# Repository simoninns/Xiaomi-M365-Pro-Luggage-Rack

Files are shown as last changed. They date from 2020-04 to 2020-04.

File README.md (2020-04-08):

# Xiaomi-M365-Pro-Luggage-Rack

A 3D printable luggage rack design for the Xiaomi M365 Pro electric scooter that does not prevent the folding down of the handlebars for carrying.

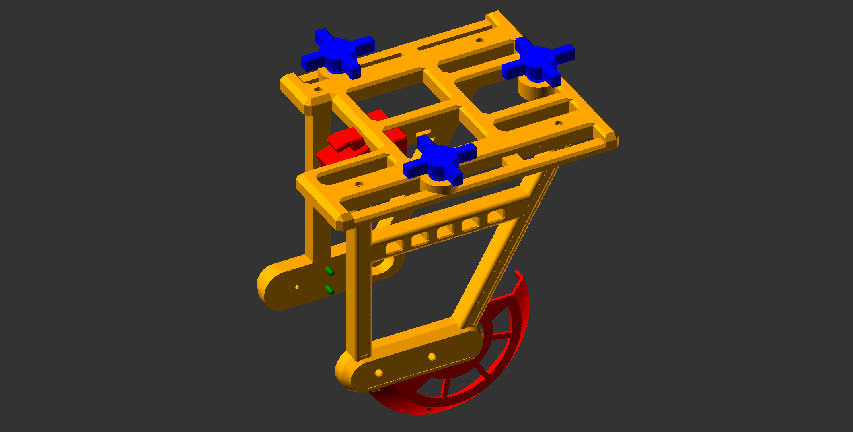
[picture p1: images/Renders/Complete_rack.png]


# Overview

The design includes a 3 part rack (left stay, right stay and rack surface) that mounts in place of the existing side covers of the M365 pro scooter.  The rack is designed to fit around the existing hardware (such as the disc brake calliper) without the need to alter any parts.  Since the rack blocks access to the original folding hook (mounted on the rear mudguard) the design includes a new hook design which is higher and placed further back to compensate for the angle of the original hook's mount.

The design requires a strong flexible plastic and is therefore suitable for filaments such as PETG and ABS.  The design requires a printer with a 20x25cm print surface.

Maximum safe weight on the rack is approximately 5Kgs



# Assembly instructions

## Required hardware

The following hardware is required for assembly (in addition to the 3D printed parts):

* M5x16mm screw (used to secure the hook in place of the original M5x10mm screw)
* M5 Nylon nut (you could use a standard nut, but be sure to thread-lock it)
* M5 spring washer
* M5 washer
* 8x M3x0.5 threaded brass inserts
* 6x M3x10 screws
* Superglue
* Red Reflective tape 20mm wide
* Craft knife

## Assembly

### Basic mounting

Remove the mudguard and the original hook.  Place the new hook in the same place using the M5x16mm screw.  The order should be screw, spring washer, washer, mudguard then hook.  Note that the hook is designed so you can fit a 5mm spanner into the hook to tighten the nylon bolt.

Remove the original side covers.  Glue 2 support pins into the centre holes of the rack stays.  Insert two M3 brass inserts into each stay using a hot iron (such as a soldering iron) - ensure the insert is straight and flush with the surface.  Superglue two support pins into each stay.  Affix the left and right rack stays using the original hex screws (use thread-lock).

Press the rack surface onto the left and right stays as well as down into the 'U' mount of the hook (this should be easy to do and not require any force).  Screw into place using 4x M3x10 screws (use thread-lock).

Note that the left stay and the rack surface have two additional slots each for M3 brass inserts (on the base of the stay, and under the rear of the surface).  These are for attaching additional accessories such as a disc guard.

Apply the reflective tape to the sides and back of the rack (as shown in the pictures).  The main reflective location is designed to take the full 20mm wide tape.  For the stay struts and the back of the rack surface you will need to carefully cut thin strips of tape and affix.

### Box fastener

In order to easily carry larger objects it is useful to affix a small plastic box to the rack (cheap plastic boxes with sealable lids can be sourced from many supermarkets and hardware stores).  To make this easy the rack has 3 threaded holes.  Print the 3 fasteners and drill holes in the box to allow them to pass through.  Ensure the box is as central on the rack as possible (without excessive overhang on the sides of the rack).  Mount the box using the 3 fasteners.  The box can be easily removed when not required or if you need to fold the scooter for transport.



### Disc guard

The disc guard is designed to protect the disc brake rotor from impact damage as well as large stones etc.  To fit the disc guard use 2 M3x16 screws and attach to the left rack stay using the provided M3 fittings underneath the stay.

# Printing instructions

## Overview

The model has been printed and tested on the Prusa MK3S/MMU2S printer using PETG filament. All parts fit on a 20x25 printing bed.

The OpenSCAD source files provide a parameter interface that allows you to render either the whole model or the individual parts (placed flat on the axis ready for STL (or other 3D format) export).  This requires OpenSCAD 2019.05 or later.

The github repository for the model can be found at https://github.com/simoninns/Xiaomi-M365-Pro-Luggage-Rack

## Recommended print settings
### Rack surface
* Number required: 1
* Material: Prusament PETG (Prusa Jet Black)
* Layer: 0.20mm (Quality)
* Infill: 20%
* Supports: Support on build plate only
* Print time (approximate): 10h 59m
* Notes: None

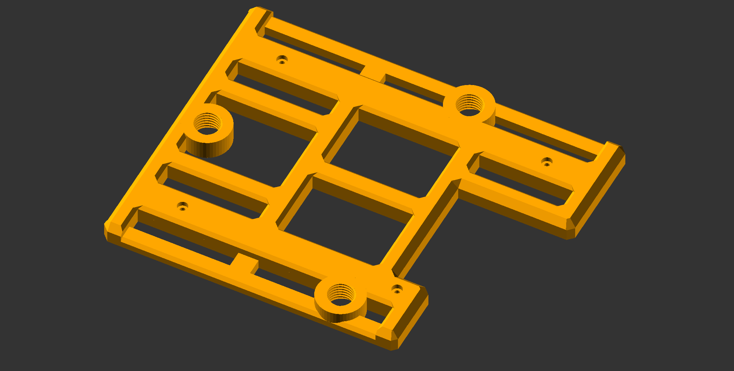
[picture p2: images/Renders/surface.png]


### Rack left
* Number required: 1
* Material: Prusament PETG (Jet Black)
* Layer: 0.20mm (Quality)
* Infill: 20%
* Supports: None
* Print time (approximate): 6h 0m
* Notes: Due to the configuration of the disc brake and the handlebars, the left and right rack stays are not the same size.

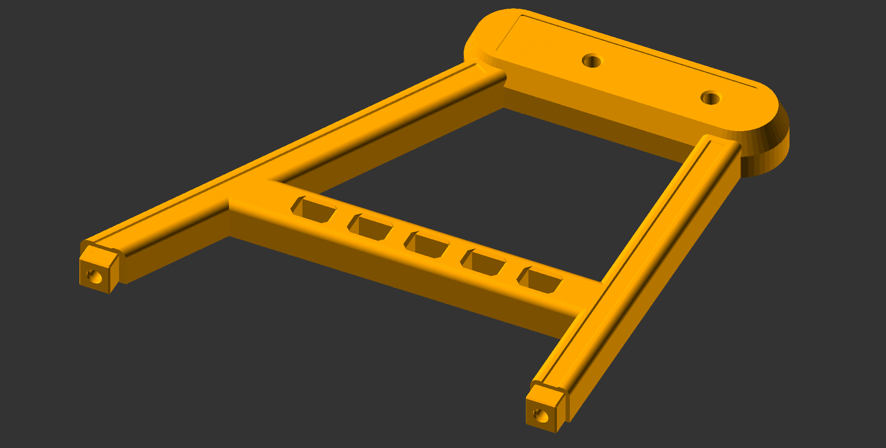
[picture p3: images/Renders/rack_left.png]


### Rack right
* Number required: 1
* Material: Prusament PETG (Jet Black)
* Layer: 0.20mm (Quality)
* Infill: 20%
* Supports: None
* Print time (approximate): 5h 33m
* Notes: Due to the configuration of the disc brake and the handlebars, the left and right rack stays are not the same size.



### Hook
* Number required: 1
* Material: Prusament PETG (Prusa Orange)
* Layer: 0.20mm (Quality)
* Infill: 50%
* Supports: Everywhere
* Print time (approximate): 2h 36m
* Notes: The hook should be printed on it's side to ensure the print layers are 90 degrees from the direction of force when lifting the scooter.  This requires the use of supports 'everywhere' due to the shape.

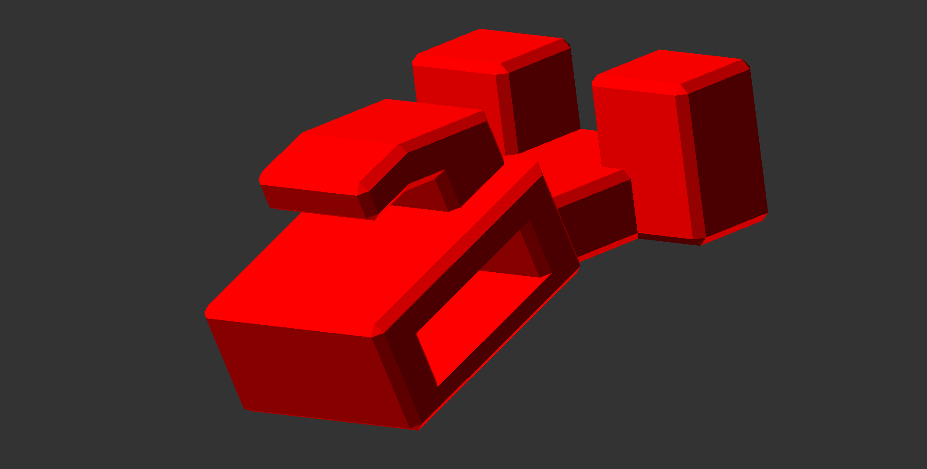
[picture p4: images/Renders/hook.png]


### Support pins
* Number required: 1 (includes 4 pins per print)
* Material: Prusament PETG (Prusa Orange)
* Layer: 0.20mm (Quality)
* Infill: 50%
* Supports: None
* Print time (approximate): 0h 15m
* Notes: To prevent the pins falling over during printing, turn on brim and set to 10mm.

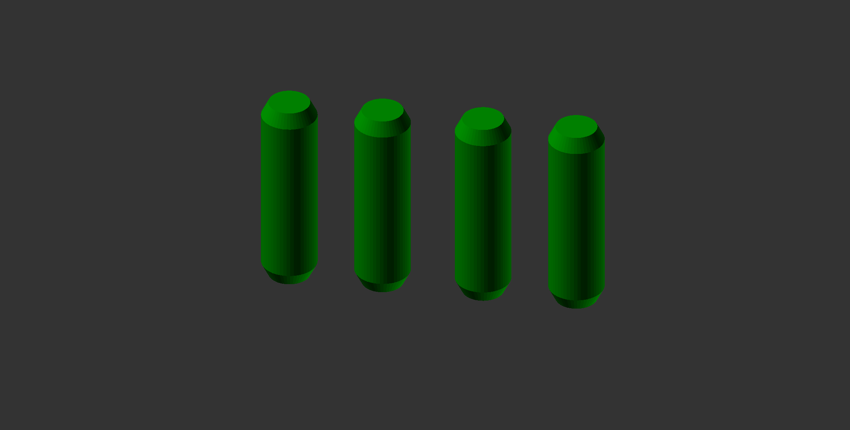
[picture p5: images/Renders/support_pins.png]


### Box fasteners
* Number required: 1 (includes 3 fasteners per print)
* Material: Prusament PETG (Prusa Orange)
* Layer: 0.20mm (Quality)
* Infill: 25%
* Supports: None
* Print time (approximate): 3h 4m
* Notes: These are only required if you wish to affix a box to the rack surface.  The fastener threads are 0.25mm smaller in diameter than the threads on the rack surface to allow for printing tolerance.  This is a pretty tight fit to begin with and you may need to insert and remove them several times to make the threads correctly mate.  If insertion into the rack is too tight, either scale the print slightly or alter the design files according to your 3D printer. Alternatively, lightly sand the fastener's thread until it fits correctly.

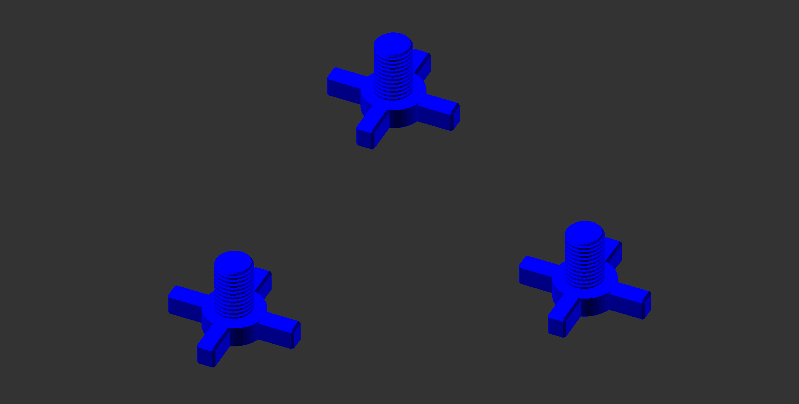
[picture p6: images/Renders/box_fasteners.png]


### Disc guard
* Number required: 1
* Material: Prusament PETG (Prusa Orange)
* Layer: 0.20mm (Quality)
* Infill: 15%
* Supports: None
* Print time (approximate): 2h 10m
* Notes: This part is optional.

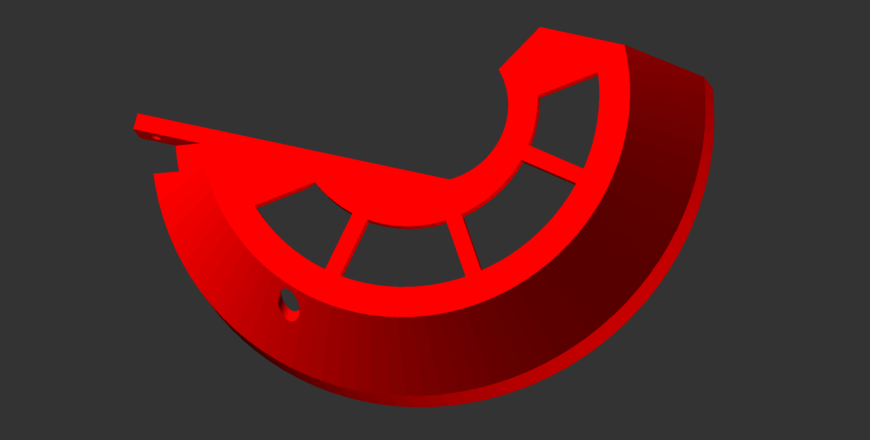
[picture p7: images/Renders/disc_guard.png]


# Author

The Xiaomi M365 Pro Luggage Rack is designed and maintained by Simon Inns.

# Licensing

## OpenSCAD source files - software license (GPLv3)

    This is free software: you can redistribute it and/or modify
    it under the terms of the GNU General Public License as published by
    the Free Software Foundation, either version 3 of the License, or
    (at your option) any later version.
    
    This program is distributed in the hope that it will be useful,
    but WITHOUT ANY WARRANTY; without even the implied warranty of
    MERCHANTABILITY or FITNESS FOR A PARTICULAR PURPOSE.  See the
    GNU General Public License for more details.
    
    You should have received a copy of the GNU General Public License
    along with this program.  If not, see <http://www.gnu.org/licenses/>.

## 3D model file - Creative Commons license (Creative Commons BY-SA 4.0)

Please see the following link for details: https://creativecommons.org/licenses/by-sa/4.0/

You are free to:

Share - copy and redistribute the material in any medium or format
Adapt - remix, transform, and build upon the material
for any purpose, even commercially.

This license is acceptable for Free Cultural Works.

The licensor cannot revoke these freedoms as long as you follow the license terms.

Under the following terms:

Attribution - You must give appropriate credit, provide a link to the license, and indicate if changes were made. You may do so in any reasonable manner, but not in any way that suggests the licensor endorses you or your use.

ShareAlike - If you remix, transform, or build upon the material, you must distribute your contributions under the same license as the original.

No additional restrictions - You may not apply legal terms or technological measures that legally restrict others from doing anything the license permits.

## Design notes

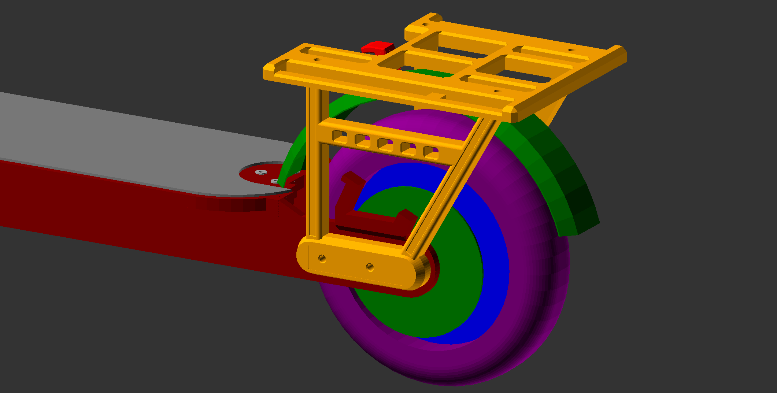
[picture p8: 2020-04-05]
images/Renders/Leftside_full.png

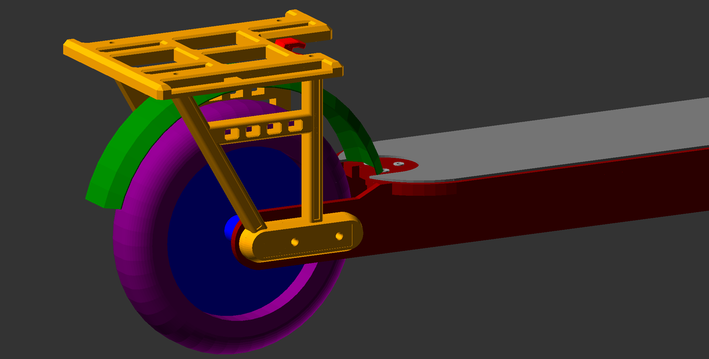
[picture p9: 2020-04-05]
images/Renders/Rightside_full.png

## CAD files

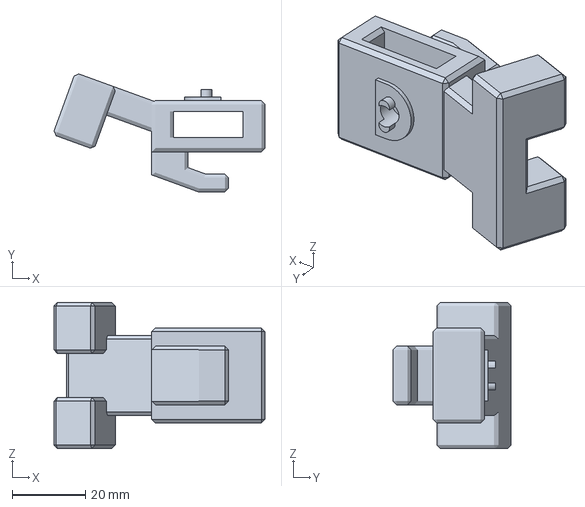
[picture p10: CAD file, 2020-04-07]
3mf/hook.3mf
57.7 x 32.3 x 40.0 mm

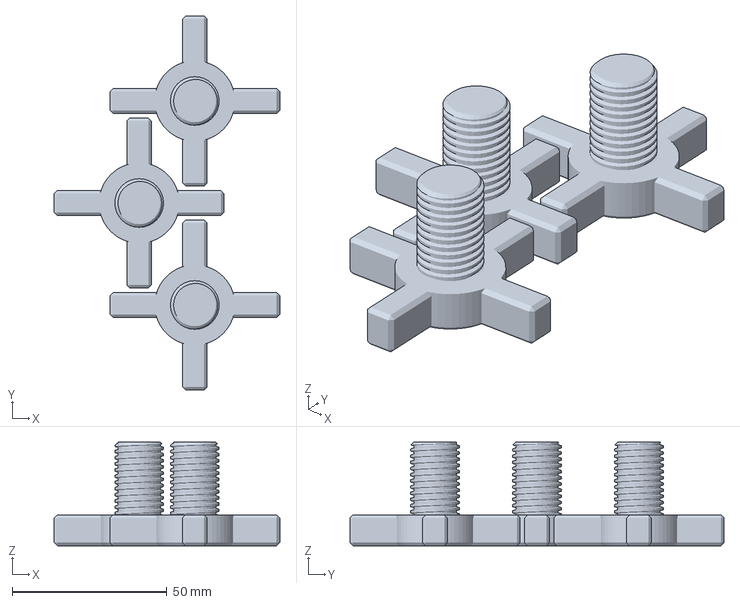
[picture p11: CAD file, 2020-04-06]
3mf/box_fasteners.3mf
73.0 x 121.0 x 33.5 mm

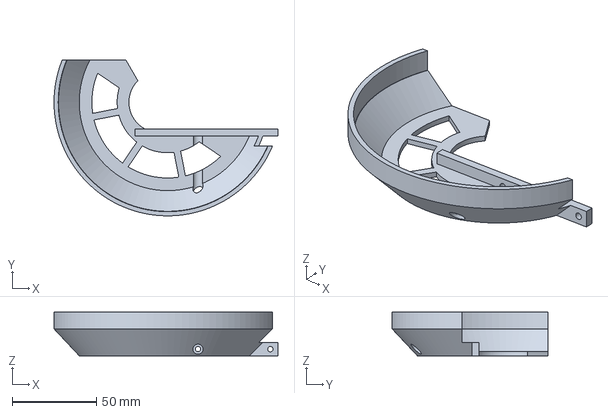
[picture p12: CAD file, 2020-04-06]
3mf/disc_guard.3mf
133.0 x 92.5 x 26.0 mm

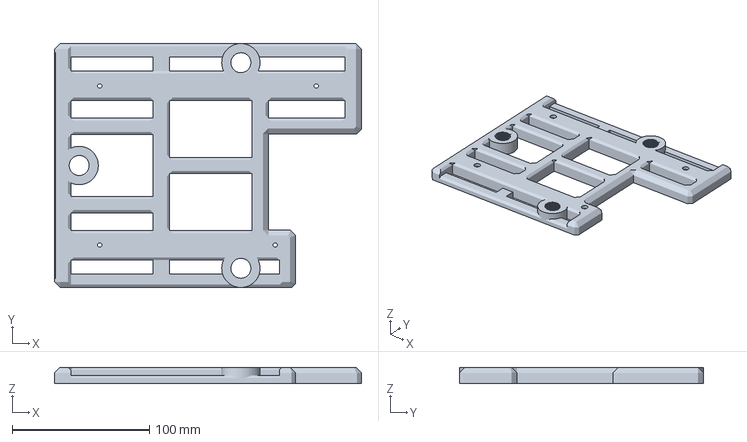
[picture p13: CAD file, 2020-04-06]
3mf/surface.3mf
224.0 x 178.0 x 12.0 mm

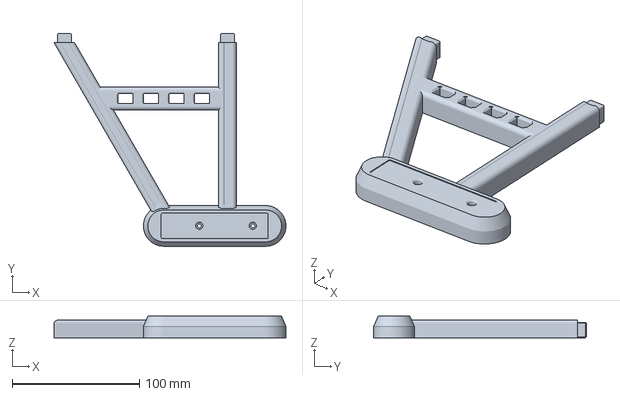
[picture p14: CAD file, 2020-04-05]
3mf/rack_right.3mf
182.2 x 167.0 x 17.0 mm

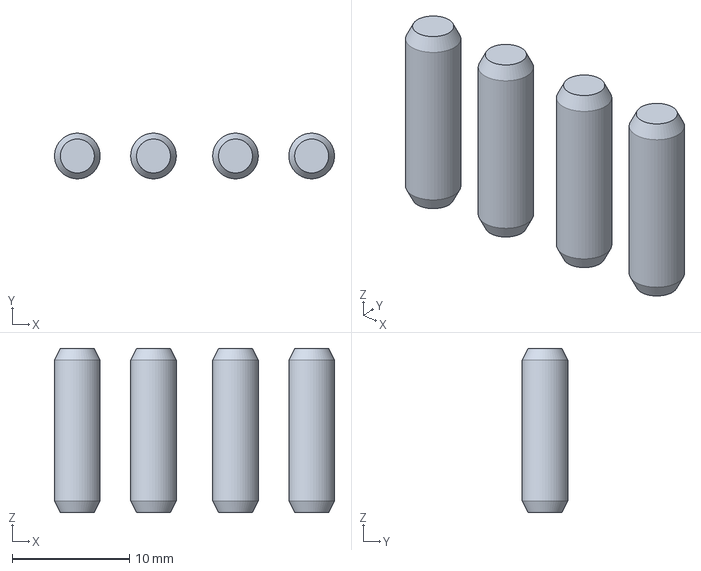
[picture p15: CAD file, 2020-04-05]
3mf/support_pins.3mf
23.9 x 3.89 x 14.0 mm

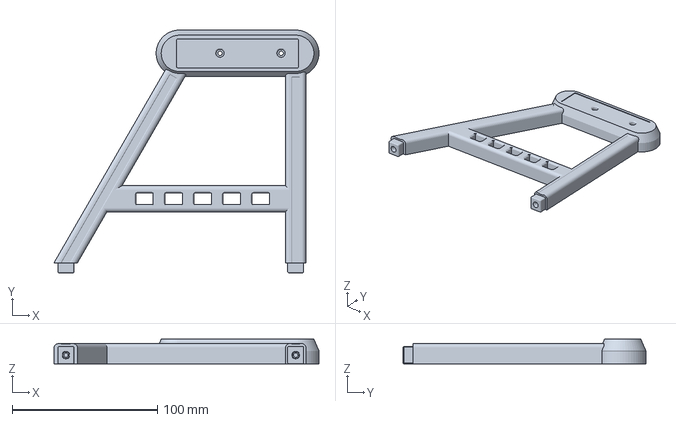
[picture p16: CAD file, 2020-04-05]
3mf/rack_left.3mf
182.2 x 167.0 x 17.0 mm

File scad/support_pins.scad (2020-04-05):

/************************************************************************

	support_pins.scad
    
	Xiaomi M365 Pro Luggage rack
    Copyright (C) 2020 Simon Inns
    
    This program is free software: you can redistribute it and/or modify
	it under the terms of the GNU General Public License as published by
	the Free Software Foundation, either version 3 of the License, or
	(at your option) any later version.
    
    This program is distributed in the hope that it will be useful,
    but WITHOUT ANY WARRANTY; without even the implied warranty of
    MERCHANTABILITY or FITNESS FOR A PARTICULAR PURPOSE.  See the
    GNU General Public License for more details.
    
    You should have received a copy of the GNU General Public License
    along with this program.  If not, see <http://www.gnu.org/licenses/>.
	
    Email: simon.inns@gmail.com
    
************************************************************************/

include <BOSL/constants.scad>
use <BOSL/shapes.scad>
use <BOSL/transforms.scad>

// Note: This part is load-bearing and should be printed
// with 25% in-fill.  Use a 10mm brim and print up-right.

// Note: Side cover hole is 4mm diameter and 6mm deep
//       Frame is 7mm thick behind the cover
module support_pin()
{
    color("green") {
        cyl(h = 6 + 7 + 1 - 2, d = 3.9);

        move([0,0,6.5]) cyl(h = 1, d1 = 3.9, d2 = 2.9);
        move([0,0,-6.5]) cyl(h = 1, d1 = 2.9, d2 = 3.9);
    }
}

module render_support_pins(render_for_display)
{
    if (render_for_display) {
        // Left
        rotate([90,0,0]) move([41,8,-45 - 6]) support_pin();
        rotate([90,0,0]) move([41,-8,-45 - 6]) support_pin();

        // Right
        rotate([90,0,0]) move([41,8,+45 + 6]) support_pin();
        rotate([90,0,0]) move([41,-8,+45 + 6]) support_pin();
    } else {
        move([-10,0,7]) support_pin();
        move([-3.5,0,7]) support_pin();
        move([3.5,0,7]) support_pin();
        move([10,0,7]) support_pin();
    }
}

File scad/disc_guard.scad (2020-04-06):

/************************************************************************

	disc_guard.scad
    
	Xiaomi M365 Pro Luggage rack
    Copyright (C) 2020 Simon Inns
    
    This program is free software: you can redistribute it and/or modify
	it under the terms of the GNU General Public License as published by
	the Free Software Foundation, either version 3 of the License, or
	(at your option) any later version.
    
    This program is distributed in the hope that it will be useful,
    but WITHOUT ANY WARRANTY; without even the implied warranty of
    MERCHANTABILITY or FITNESS FOR A PARTICULAR PURPOSE.  See the
    GNU General Public License for more details.
    
    You should have received a copy of the GNU General Public License
    along with this program.  If not, see <http://www.gnu.org/licenses/>.
	
    Email: simon.inns@gmail.com
    
************************************************************************/

include <BOSL/constants.scad>
use <BOSL/shapes.scad>
use <BOSL/metric_screws.scad>
use <BOSL/transforms.scad>
use <BOSL/paths.scad>

module disc_guard()
{
    depth = 26;

    move([0,50 +12,0]) {
        rotate([90,0,0]) {
            difference() {
                union() {
                    difference() {
                        move([0,0,23]) cyl(l=10, d1=135, d2=135);
                        move([0,0,23]) cyl(l=10+2, d1=130, d2=130);
                    }

                    difference() {
                        move([0,0,24 - 14]) cyl(l=16, d1=105, d2=135);
                        move([0,0,27 - 14]) cyl(l=17, d1=105, d2=136);
                    }
                }

                // Front frame cutout
                move([60,-16,20]) cuboid([20,20,20]);

                // Front top cutout
                move([0,65,12]) cuboid([140,80,40]);
                move([30,13,12]) cuboid([80,40,40]);

                // Centre hub cutout
                move([35,0,0]) slot([-40,0,0], [+40,0,0], r1=18, r2=18, h=40);

                // Back angle cut
                move([-19,30,12]) rotate([0,0,-60]) cuboid([40,15,40]);

                // Access for screwdriver
                move([18,-50,6]) rotate([90,0,0]) cyl(h=60, d=6);
                
                // Rotational cut-out pattern
                rotate([0,0,11]) move([0,0,-9]) difference() {
                    move([0, 0 ,0 + (depth / 2)]) cyl(l=8, d=90);
                    move([0, 0 ,0 + (depth / 2)]) cyl(l=9, d=60);

                    move([0, 0 ,0 + (depth / 2)]) rotate([0,0,-45]) cuboid([4,150,10]);
                    move([0, 0 ,0 + (depth / 2)]) rotate([0,0,0]) cuboid([4,150,10]);
                    move([0, 0 ,0 + (depth / 2)]) rotate([0,0,+45]) cuboid([18,150,10]);
                    move([0, 0 ,0 + (depth / 2)]) rotate([0,0,+90]) cuboid([4,150,10]);

                    rotate([0,0,45]) move([23,0,12]) cuboid([50,150,15]);
                }
            }

            difference() {
                // Bracket
                move([23,-18,6]) cuboid([85,4,8], chamfer = 0, edges=EDGE_TOP_BK);

                // Screw holes
                move([18,-18,6]) rotate([90,0,0]) cyl(h=10, d=3.2);
                move([61,-18,6]) rotate([90,0,0]) cyl(h=10, d=3.2);
            }
        }
    }    
}

module disc_guard_screws()
{
    // Screws are M3x10mm
    rotate([0,180,0]) {
        move([-18,56,20]) screw(screwsize=3,screwlen=10,headsize=6,headlen=3, align="base");
        move([-18 - 43,56,20]) screw(screwsize=3,screwlen=10,headsize=6,headlen=3, align="base");
    }
}

module render_disc_guard(render_for_display)
{
    $fn = 100;
    if (render_for_display) {
        color("red") disc_guard();
        color("grey") disc_guard_screws();
    } else {
        rotate([-90,0,0]) move([0,-61,0]) color("red") disc_guard();
    }
}

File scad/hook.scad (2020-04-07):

/************************************************************************

	hook.scad
    
	Xiaomi M365 Pro Luggage rack
    Copyright (C) 2020 Simon Inns
    
    This program is free software: you can redistribute it and/or modify
	it under the terms of the GNU General Public License as published by
	the Free Software Foundation, either version 3 of the License, or
	(at your option) any later version.
    
    This program is distributed in the hope that it will be useful,
    but WITHOUT ANY WARRANTY; without even the implied warranty of
    MERCHANTABILITY or FITNESS FOR A PARTICULAR PURPOSE.  See the
    GNU General Public License for more details.
    
    You should have received a copy of the GNU General Public License
    along with this program.  If not, see <http://www.gnu.org/licenses/>.
	
    Email: simon.inns@gmail.com
    
************************************************************************/

include <BOSL/constants.scad>
use <BOSL/shapes.scad>
use <BOSL/metric_screws.scad>
use <BOSL/transforms.scad>

// Note: This part is load-bearing and should be printed
// on its side with 25% in-fill.

// Render the base of the hook
// (This is the attachment into the read mudguard)
module hook_base()
{
    difference() {
        union() {
            difference() {
                move([1,0,0.5]) slot([0,0,0], [7,0,0], d1=14, d2=14, h=1);
                move([11.5,0,0.5]) cuboid([15,17,4]);
            }

            difference() {
                move([0,0,-1]) slot([0,-2.5,0], [0,2.5,0], d1=3, d2=3, h=2);
            }
        }
        move([0,0,-0.5]) cyl(h=5, d=5.2);
    }
}

module hook_bot_middle()
{
    p = 2.5; // z position
    h = 3; // z height

    difference() {
        move([0.5,0,p]) cuboid([31,26,h], chamfer = 1, edges = EDGES_BOTTOM+EDGES_Z_ALL);
        move([0,0,p - (h/2) + 0.1]) cyl(h=h*2, d=5.2);
    }
}

module hook_top_middle()
{
    p = 7.5; // z position
    h = 7; // z height

    move([-12,0,p]) cuboid([6,26,h], chamfer = 1, edges = EDGES_Z_ALL);
    move([+13,0,p]) cuboid([6,26,h], chamfer = 1, edges = EDGES_Z_ALL);
}

module hook_top()
{
    p = 13; // z position

    union() {
        difference() {
            move([0.5,0,p]) cuboid([31,26,4], chamfer = 1, edges = EDGE_FR_LF+EDGE_FR_RT+EDGE_BK_LF+EDGE_BK_RT+
                EDGE_TOP_RT+EDGE_TOP_FR+EDGE_TOP_BK);

            move([0,0,p-2]) cyl(h=2, d=5.2);
        }

        move([-10,0,p + 5]) cuboid([10,16,8], chamfer = 1, edges = EDGES_Z_ALL);
        move([-4.5,0,p + 10.5]) cuboid([21,16,5], chamfer = 1, edges = EDGES_ALL);
    }
}

module hook_rack_support()
{
    rotate([0,-20,0]) {
        move([-22,0,10]) cuboid([25,22,8], chamfer = 1, edges = EDGES_ALL);
        move([-30,0,10]) cuboid([12,16 + 24,8], chamfer = 1, edges = EDGES_ALL);
        move([-30,13,17]) cuboid([12,14,14], chamfer = 1, edges = EDGES_ALL);
        move([-30,-13,17]) cuboid([12,14,14], chamfer = 1, edges = EDGES_ALL);
    }

}

module hook()
{
    // Note: Hook angle on mudguard is 20 degrees
    rotate([0,0,0]) {
        difference() {
            union() {
                hook_base();
                hook_bot_middle();
                hook_top_middle();
                hook_top();

                hook_rack_support();
            }

            // Flatten the top of the hook in line with the rack surface
            move([0,0,27 + 4]) rotate([0,-20,0]) cuboid([40,18,8]);

            // Chamfer the angled edges of the hook
            move([0,16,27 + 3]) rotate([0,-20,0]) cuboid([40,18,8], chamfer = 1);
            move([0,-16,27 + 3]) rotate([0,-20,0]) cuboid([40,18,8], chamfer = 1);
        }

        move([0,0,27 - 4]) rotate([0,-20,0]) {
            move([-5,0,0]) cuboid([10,16,3.5], chamfer = 1, edges = EDGES_BOTTOM);
        }
    }
}

module m5_screw()
{
    rotate([0,180,0]) {
        // M5x16
        move([0,0,5]) screw(screwsize=5,screwlen=16,headsize=10,headlen=4,countersunk=false);
        move([0,0,-8]) metric_nut(size=5, hole=true);
    }
}

module render_hook(render_for_display)
{
    if (render_for_display) {
        move([51.5,0,130]) {
            rotate([0,20,0]) {
                color("red") hook();
                color("grey") m5_screw();
            }
        }
    } else {
        rotate([90,0,0]) move([0,8,-10]) color("red") hook();
    }
}

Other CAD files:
scad/box_fastener.scad
scad/BOSL/acme_screws.scad
scad/BOSL/beziers.scad
scad/BOSL/compat.scad
scad/BOSL/constants.scad
scad/BOSL/convex_hull.scad
scad/BOSL/debug.scad
scad/BOSL/involute_gears.scad
scad/BOSL/joiners.scad
scad/BOSL/linear_bearings.scad
scad/BOSL/masks.scad
scad/BOSL/math.scad
scad/BOSL/metric_screws.scad
scad/BOSL/nema_steppers.scad
scad/BOSL/paths.scad
scad/BOSL/phillips_drive.scad
scad/BOSL/quaternions.scad
scad/BOSL/shapes.scad
scad/BOSL/sliders.scad
scad/BOSL/threading.scad
scad/BOSL/torx_drive.scad
scad/BOSL/transforms.scad
scad/BOSL/triangulation.scad
scad/BOSL/wiring.scad
scad/m3insert.scad
scad/main.scad
scad/mudguard.scad
scad/rack.scad
scad/rear_frame.scad
scad/side_cover.scad
scad/top_bracket.scad
stl/box_fasteners.stl
stl/disc_guard.stl
stl/hook.stl
stl/rack_left.stl
stl/rack_right.stl
stl/support_pins.stl
stl/surface.stl

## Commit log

2020-04-01 Add initial project files
    [main.scad, mudguard.scad, rack.scad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]
2020-04-01 Correctly add BOSL files
    [acme_screws.scad, beziers.scad, compat.scad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]
2020-04-01 Updates to side and surface of rack
    [m3insert.scad, main.scad, rack.scad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]
2020-04-02 Added M3 brass inserts and some minor bug fixes
    [m3insert.scad, main.scad, rack.scad]
2020-04-02 Fix to right stay decoration to correctly match left stay
    [rack.scad]
2020-04-02 Raised rack surface by 12mm and extended side stays
    [mudguard.scad, rack.scad]
2020-04-02 Updated, wider rack surface
    [rack.scad]
2020-04-02 Smooth edges of attachment post tips for easier insertion into rack surface
    [rack.scad]
2020-04-03 New rack surface design - less material, bars for attaching hooks
    [rack.scad]
2020-04-04 Modifications to rack surface after test printing
    [rack.scad]
2020-04-04 Added new folding hook design with extended height
    [hook.scad, main.scad, mudguard.scad]
2020-04-04 Added M3 inserts to left frame for attaching accessories
    [hook.scad, mudguard.scad, rack.scad]
2020-04-04 Minor correction to folding hook
    [hook.scad]
2020-04-04 New print mode, new hook design, added start of disc brake protector
    [disc_guard.scad, hook.scad, main.scad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]
2020-04-05 New hook design, corrected mudguard hook angle, additional work to disc guard
    [disc_guard.scad, hook.scad, mudguard.scad]
2020-04-05 Finalised hook design
    [hook.scad]
2020-04-05 Added side-cover support pins
    [main.scad, support_pins.scad]
2020-04-05 Disc guard prototype and fix to support pin diameter
    [disc_guard.scad, support_pins.scad]
2020-04-05 Added readme and supporting photos and renders. Created STL and 3mf files.
    [hook.3mf, hook.stl, rack_left.3mf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]
2020-04-06 Added fasteners to attach box to rack
    [box_fastener.scad, fasteners.3mf, fasteners.stl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]
2020-04-06 Redesigned rack surface. Added disc guard and box fasteners.
    [box_fastener.scad, box_fasteners.3mf, box_fasteners.stl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]
2020-04-07 Improved hook design to provide far more support to the rack under load
    [hook.3mf, hook.scad, hook.stl]
